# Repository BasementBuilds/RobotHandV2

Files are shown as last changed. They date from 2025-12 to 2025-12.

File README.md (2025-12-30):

# RobotHandV2
This has most of the files relating to the code, and mechanics of the robot hand and arm band.

If you have any more detailed questions, reach out to me on instagram or email at basementbuilds48@gmail.com

This should be taken as resource for different ideas, not as a tutorial to copy exactly.
The main code is run on the esp32 on the robot hand. There is also code for the glove, and the arm band, which send messages to the main robot on how to move.

If you try to use this code for some reason, make sure anytime 2 esps need to communicate wirelessly, they have the correct mac address in the code.

Neural network:
I also included some python code and training data related to the neural network I tried making.
I also included a paper explaining the neural network that I made for a class project.

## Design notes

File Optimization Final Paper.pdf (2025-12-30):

Using Gradient Descent to Optimize A Neural Network For Classification of Hand Gestures

Abstract

Electric prosthetic hands are typically controlled using two electromyography sensors. While they have been used for decades, they exhibit significant disadvantages that recent research has tried to solve using arrays of force sensors. To convert these signals into accurate predictions of the hand gesture the user is attempting to make, an algorithm such as an artificial neural network must be used. This paper details the process of training a neural network to accurately predict hand gestures based on sensor data using the method of steepest gradient descent. Overall, the method was successful, in correctly classifying 91% of signals, although further research would be beneficial in further improving the accuracy of the model.

Motivating problem

Most modern powered prosthetic hands are controlled by the user through EMG (electromyography) signals. Typically, two sensors are placed on the user's residual forearm, and by flexing one of the two main forearm muscles, the user can ‘swipe through’ a set of pre-programmed hand grips/gestures.

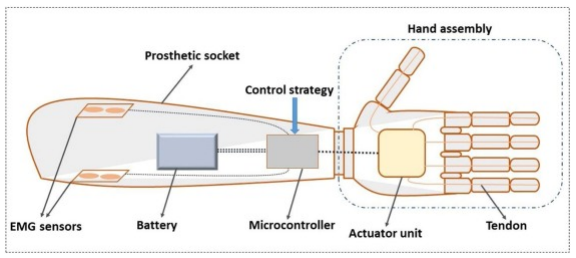
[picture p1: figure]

This has been a relatively reliable method of control for decades now, however it comes with its own drawbacks. Many users say that the complication of switching to the correct grip, and lack of fine control of their prosthetic are the main reason they dislike their prosthetic or avoid using it (1). Additionally, EMG signals typically have high noise, and become unreliable when misplaced or subject to moisture from sweat (2). This has led researchers to explore using force myography (FMG) (force sensors) as a replacement or supplement for EMG signals in prosthetic use. FMG sensors are cheaper, can be more densely packed in a small area, and are not affected by sweat or noise to the same degree. In order for this method to work, FMG data must be directly interpreted into hand grip selection (rather than cycling through grips).

Literature Review

A 2023 study by Rehman et. al. found that using force sensors was a viable method to predict hand gestures. In their research, a 7 sensor band using a support vector machine algorithm to classify 5 gestures had an accuracy of 91.6% (2). A similar study from the University of Windsor used the same algorithm with a slightly higher accuracy of 93% (3). A 2025 study from Meta’s Reality lab was able to achieve over 90% accuracy of gesture recognition using an EMG wristband and a neural network architecture (4). While the first two studies mentioned achieved high accuracy using the SVM algorithm, they only had a few (<10) participants, and it’s unclear how these results would transfer to a new user, one with a different physiology. The Meta study had over 6,00 participants and was only able to achieve good results for the general population by training neural networks over thousands of participants. While the model they used (neural network with over 15 layers) is far beyond what will be discussed in this paper, it proves that neural networks are powerful and scalable enough to tackle the motivating problem.

Background

In order to collect enough FMG data to predict hand gestures, an array of pressure sensors in a small area is needed. Previous research in this field has used commercially available individual force sensor resistors to accomplish this. While this has worked, a fully integrated design was chosen for its cost effectiveness and ability to increase sensor density in future iterations. The sensor mainly consists of a sheet of velostat sandwiched between two layers of rows of copper tape running perpendicularly. Velostat is a polymer impregnated with electrically conductive carbon black. As pressure is applied, the carbon black particles come closer to each other, reducing electrical resistance. Each of these ‘resistors’ is placed in series with a constant resistor forming a voltage divider circuit, as can be seen in the schematic below. Voltage is applied across both resistors, and the voltage across the constant resistor is measured by a microcontroller (ESP32), giving us the data we need to implement FMG control.

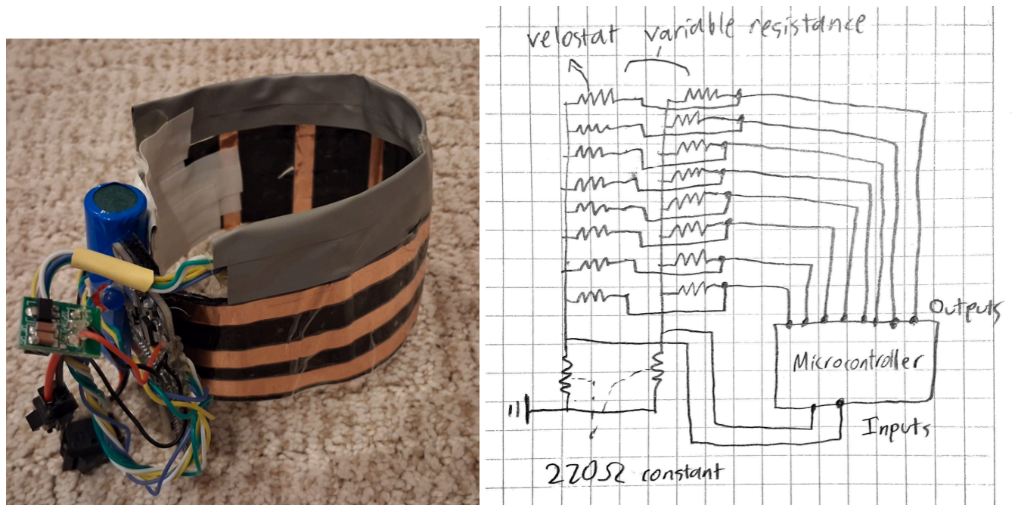
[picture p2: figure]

Below is a section of code written in the Arduino programming language that measures the voltage difference of one column of sensors (2 sensors).

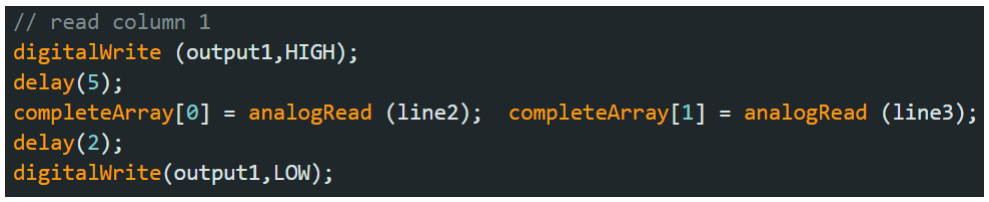
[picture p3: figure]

In order for this method to work, FMG data must be directly interpreted into hand grip selection (rather than cycling through grips). To do this, an artificial neural network (ANN) was used. An ANN connects a set of input nodes with a set of output nodes through an intermediary set of nodes often referred to as a ‘hidden layer’. Each node in a layer is taken as a weighted sum of the prior layer passed through an activation function. (each previous node is multiplied by a parameter ‘weight’, summed, added to another parameter ‘bias’ and passed through a non linear ‘activation’ function). The purpose of the activation function is to make the ANN non linear, which allows the network to better handle complex, high dimensional problems. The diagram below represents a simple neural network where the lines connecting the layers represent the weights.

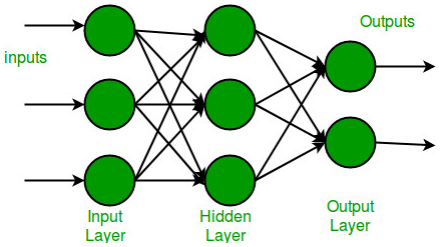
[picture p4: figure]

For the purposes of this paper, what is important to understand is that a neural network can be thought of as a very large non-linear function with many parameters (weights and biases). These parameters all must be adjusted based on training data in order to give the correct output for the given input. In concept, this can be thought of as similar to polynomial regression, where a polynomial can be fit to a set of data by tweaking the polynomial’s coefficients.
The method to adjust the ANN weights and biases is called back propagation. To train the ANN, training data (in this case, about 200 examples), which contains both the inputs and outputs, is used. The first training example input will be plugged into the neural network, with the weights and biases initially randomized. The output of the ANN will then be compared to the true output, using a cost function. The cost is a function of all of the ANN’s weights and biases. The more ‘wrong’ the ANN is in its prediction, the higher the cost will be. The gradient of the cost function can then be found, which will be explained in more detail in the approach section. The negative of the gradient shows the direction and magnitude of the changes to the weights and biases that will lead to the steepest decrease in the cost function, thus improving the accuracy of the ANN. This is a process known as steepest gradient descent. This process is then repeated for all (roughly 200) of the training examples, until the cost has reached a minimum.

Approach

The input of the neural network is the 16 FMG sensor values, and the output is 4 nodes corresponding to hand gestures (open, close, point, pinch) respectively. For example, an output of [0,0,1,0] would correspond to the ‘point’ gesture. After testing several structures, an ANN with 1 hidden layer of 18 nodes (along with an input layer of 16 nodes and output of 4 nodes) using the ‘leaky ReLu’ activation function was chosen, as it was the least computationally expensive model that worked well.

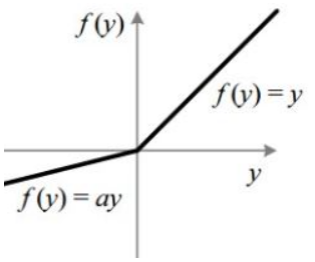
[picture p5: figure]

The graph above represents the leaky ReLu function. In this project, an (a) value of 0.1 was used.
This model has 382 weights and biases which are the design variables that must be adjusted. While the neural network can seem very complicated at first, it can be implemented relatively simply as seen by the few lines of python code below.

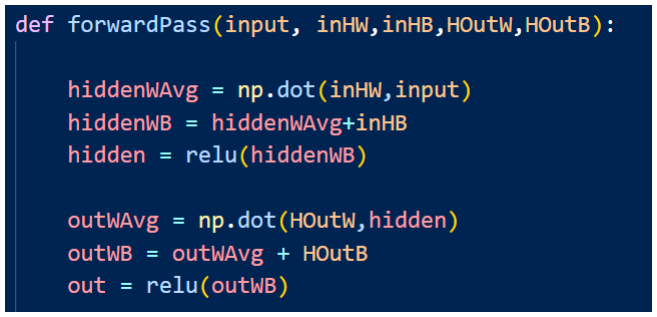
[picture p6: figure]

In the code, inHW and inHB are the weights and biases between the input and hidden layers, and HOutW and HOutB are the parameters between the hidden and output layers. The next step is to find the cost of the neural network, which is a function of all the parameters (weights and biases). This will be the objective function that we will seek to minimize. We will also add an inequality constraint to each of the weights to limit their absolute value. Research has shown that doing so helps to prevent the neural network from overfitting (5), which is represented in the diagram below.

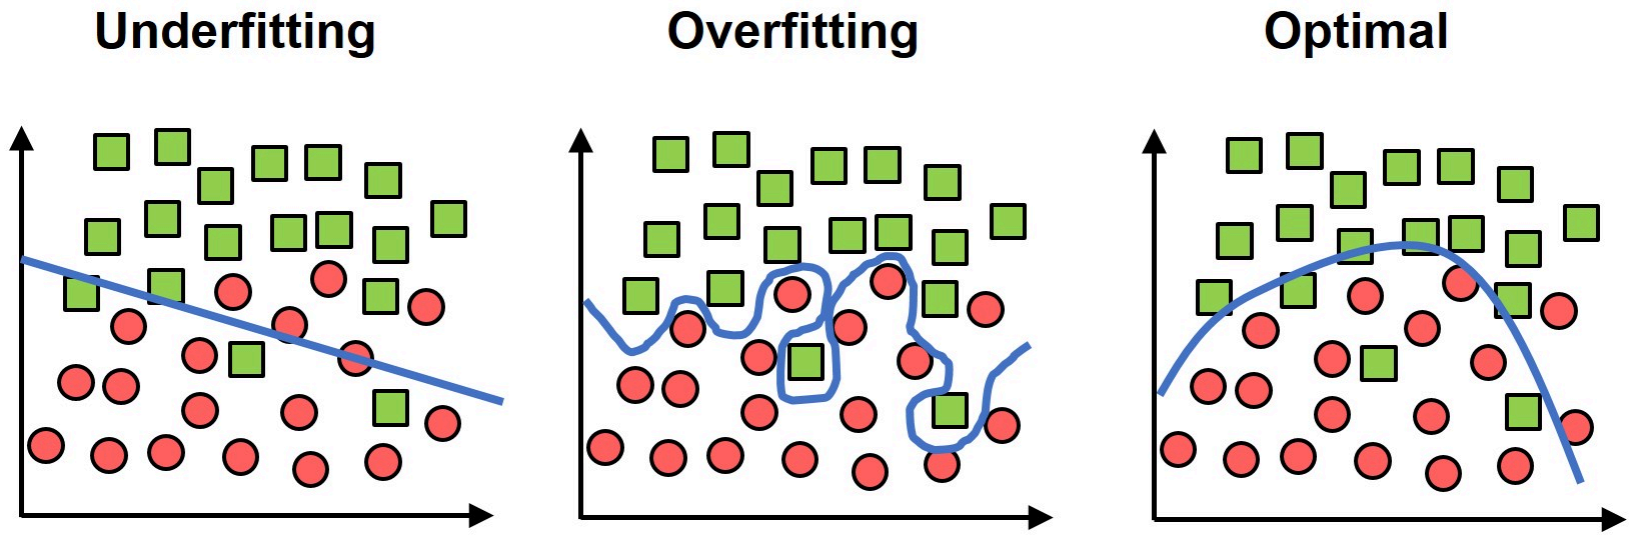
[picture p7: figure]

The optimization problem can now be expressed in the standard form as seen below, where w1 and b1 are the parameters between the input and hidden layer, and w2 and b2 are the parameters between the hidden and output layer. w1 and w2 are matrices, and b1 and b2 are vectors. In the summation steps, 4 is representative of the 4 output neurons, 1 for each hand gesture, and T represents the total number of training examples.

## Min

Subject to:

The code below calculated the cost function for a single training example, which can then be summed across the entire dataset.

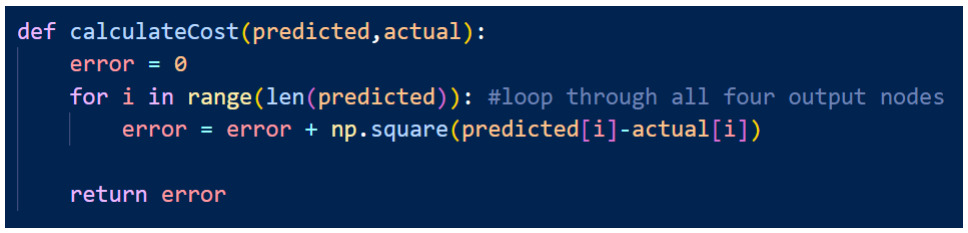
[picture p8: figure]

As previously mentioned, the approach to minimize the cost function was decided to be steepest gradient descent. The first step in this process is to determine the gradient of the cost function. The gradient in simpler terms can be thought of as the slope of the function. The gradient is a vector that for each independent variable (weights and biases), will represent the direction and magnitude of steepest ascent. For example, if a value in the gradient vector corresponding to a certain weight (Wa) is positive, that means that increasing Wa will increase the overall cost function. However, we want to minimize the cost function, so we will find the negative of the gradient. We must find the partial derivative of the cost with respect to each weight and bias.
To do this, the chain rule from calculus must be applied. The partial derivative of a weight between the hidden and output layer for example, is equal to the product of partial derivative of the cost with respect to the output node, multiplied by the partial derivative of the output node with respect to the activation function, multiplied by the partial derivative of the weighted sum (output node before it was passed through the activation function) with respect to the weight as is represented by the equation below.

Similarly, the partial derivative of the cost with respect to a bias in the output layer is given below. The last term of dz/db is equal to 1 and thus can be dropped.

The partial derivative of the cost with respect to a weight between the input and hidden layers is given below.

The partial derivative of the cost with respect to a bias in the hidden layer is given below.

The partial derivative of the cost with respect to the hidden layer node (first term in the above equations) is given below.

Below is the code that calculates the partial derivatives of the cost with respect to the parameters between the hidden and output layers.

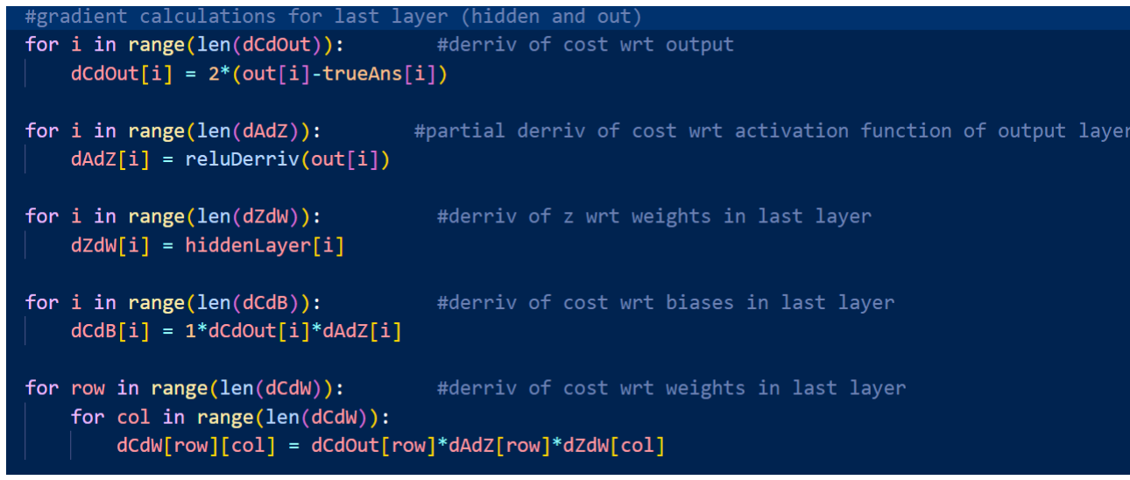
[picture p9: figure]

Likewise, the code for the partial derivatives of the cost with respect to the parameters between the input and hidden layer is given below.

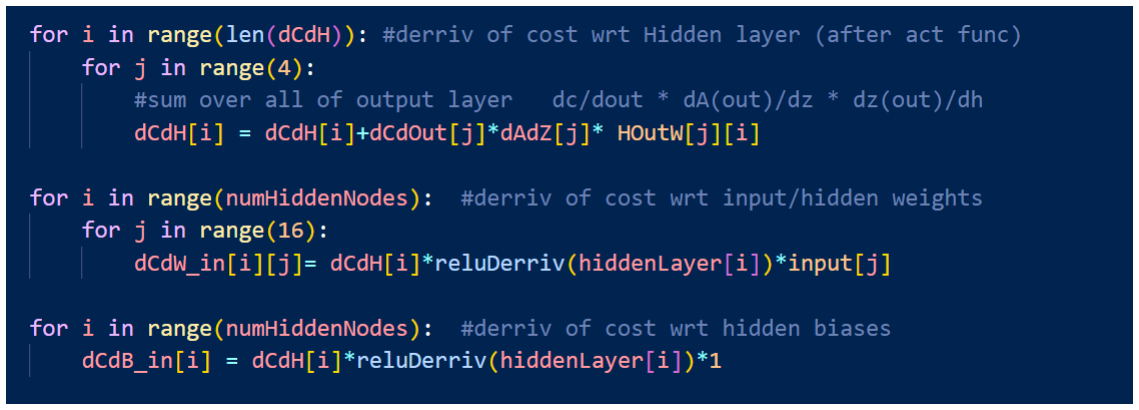
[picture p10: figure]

Once the gradient has been calculated, the next step is to adjust all 382 design variables (weights and biases) to reduce the cost function, thereby making the model overall more accurate at correctly recognizing the 4 hand gestures. The way to do this is by taking the negative of the gradient, multiplying it by a scalar (fraction to reduce magnitude, prevents oscillations and overshooting), and adding the results to the design variables. This process is repeated over all training examples, until the cost function reaches a minimum. The code to accomplish this step of gradient descent is shown below.

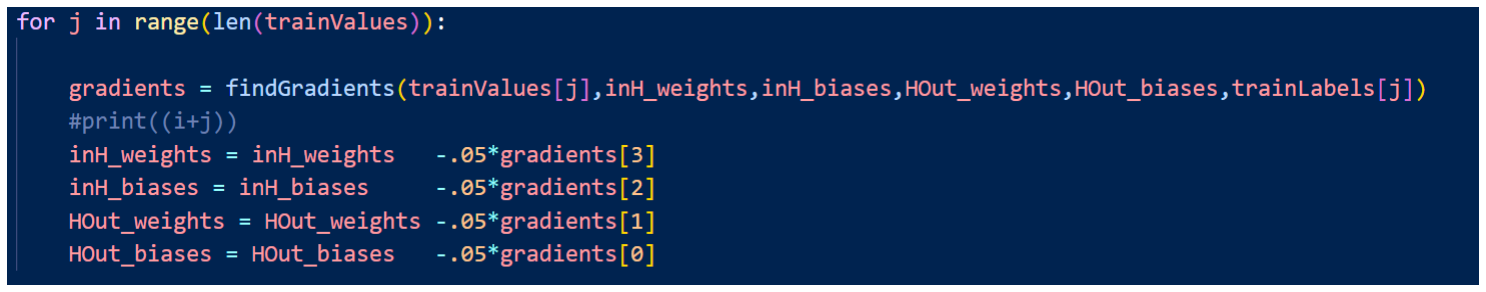
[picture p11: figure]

Here, the step size was decided to be 0.05 based on experimentation. A more analytical way to determine hyperparameters such as step size will be explored further in the results and discussion section.

Results

Overall, the method of gradient descent worked well. The graph below shows the cost of the neural network during the process of gradient descent.

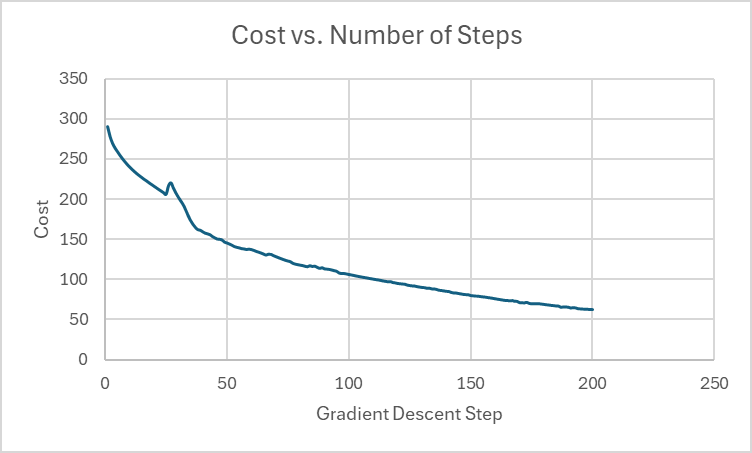
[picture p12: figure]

After 200 gradient descent steps, the cost fell from 289.8 to 62.9, which shows that the gradient descent method was effective. However, the cost is somewhat of an arbitrary number that is relative to the size of the dataset, and doesn’t directly tell us what we want to know, which is how accurate the neural network is at predicting hand gestures. To find the accuracy, a second dataset is then passed through the neural network. This ‘testing’ dataset of about 100 examples is completely separate from the training dataset, and the correct answer is not used to influence the output of the network. The accuracy of the neural network in regards to new data is shown in the graph below.

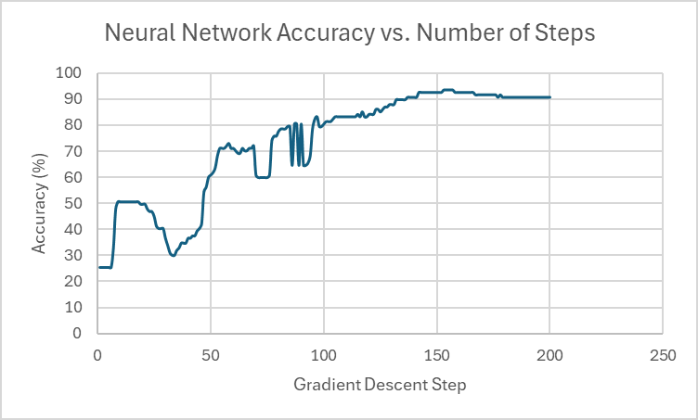
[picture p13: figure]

The accuracy increased over 200 gradient descent steps from 25.2% to 91.6%, which is in line with previous research in this field, albeit somewhat on the low side.

Discussion and Conclusion

Several interesting observations can be made from the results. While the accuracy of the network increasing while the cost decreases is to be expected, the cost decreased in a mostly smooth manner, while the accuracy oscillates somewhat erratically while trending upwards. This could be due to several factors, including small training and testing datasets, or perhaps possibly due to the network overfitting in some instances.
Another observation during testing was that the results varied across different training runs. This is somewhat expected due to the parameters initially being randomized. However, the network in some cases was unable to improve accuracy in a meaningful way, as seen by the graphs below.

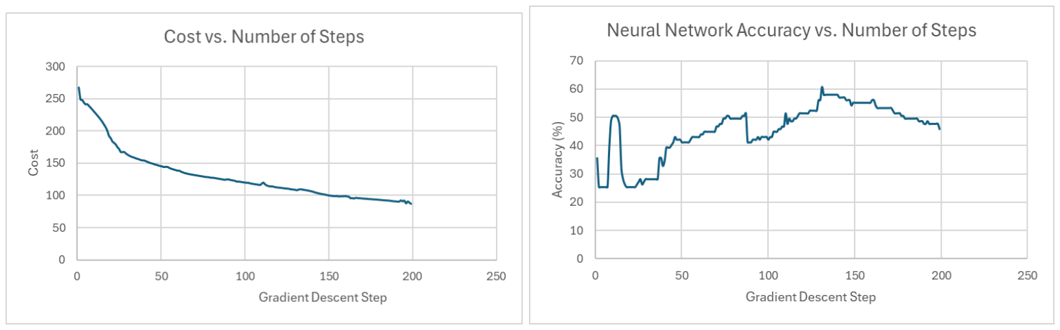
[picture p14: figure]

Here, the model plateaued at an accuracy of only 46%. This could be due to the model optimizing into a high local minimum, rather than a global minimum, which can be visualized by the image below.

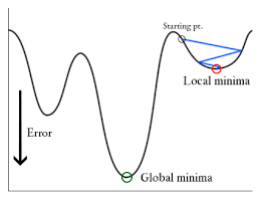
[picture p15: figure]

A third observation can be made in regards to the actual parameters of the network. Neural networks are typically thought of as a ‘black box’ that are impossible to understand the inner workings of. This is especially true of deep learning models with dozens of layers and millions of parameters, but this model is relatively small, and interesting effects can be observed. From a small selection of input data (seen below), we can see that some sensors change more than others based on the grip pattern. Here, it can be noticed that the first sensor varies significantly, over 200 units between different grips, while the sixteenth sensor only varies a couple of units between grips.

After training the model, the difference in weight values of the two sensors was measured. The sum of changes to weights connected to the first sensor node was 39.2, while the sum of changes to the sixteenth sensor was only 20.6. If we observe individual weights, it becomes clear that the neural network ‘decided’ that the first sensor should be more influential than the sixteenth sensor. For example, the weight connecting the first sensor to the sixth hidden node changed from -.62 to 7.75. The corresponding weight for the sixteenth sensor only changed from 0.59 to 1.0.

While this paper demonstrated that a neural network could be used to accurately classify hand gestures, more research needs to be done to improve accuracy and make this solution commercially viable. Many of the ‘hyper’ parameters of the network such as number of layers, number of hidden nodes, activation function, and step size were chosen through simple trial and error, or randomly. These hyper parameters could be in themselves optimized, through methods such as genetic algorithms. Further optimization could also be done to the physical sensor arm band, which showed promising results for future research.

References

1. Pylatiuk C, Schulz S, Döderlein L. Results of an Internet survey of myoelectric prosthetic hand users. Prosthet Orthot Int. 2007 Dec;31(4):362-70. doi:
10.1080/03093640601061265. PMID: 18050007.\
2. Rehman, M. U., Shah, K., Haq, I. U., Iqbal, S., Ismail, M. A., & Selimefendigil, F. (2023). Assessment of Low-Density Force Myography Armband for Classification of Upper Limb Gestures. Sensors, 23(5), 2716. https://doi.org/10.3390/s23052716
3. M. Anvaripour and M. Saif, "Hand gesture recognition using force myography of the
| forearm activities and optimized features," 2018 IEEE International Conference on
| Industrial Technology (ICIT), Lyon, France, 2018, pp. 187-192, doi:
| 10.1109/ICIT.2018.8352174. keywords: {Feature
| extraction;Sensors;Muscles;Optimization;Mathematical model;Gesture
| recognition;Support vector machines;Force Myography;Hand gestures;Feature
| extraction;Multiobjective optimization},
4. Kaifosh, P., Reardon, T.R. & CTRL-labs at Reality Labs. A generic non-invasive
| neuromotor interface for human-computer interaction. Nature 645, 702–711 (2025).
| https://doi.org/10.1038/s41586-025-09255-w
5. Brownlee, Jason. “A Gentle Introduction to Weight Constraints in Deep Learning.”
| MachineLearningMastery.Com, 6 Aug. 2019,
| machinelearningmastery.com/introduction-to-weight-constraints-to-reduce-generalization
| -error-in-deep-learning/.

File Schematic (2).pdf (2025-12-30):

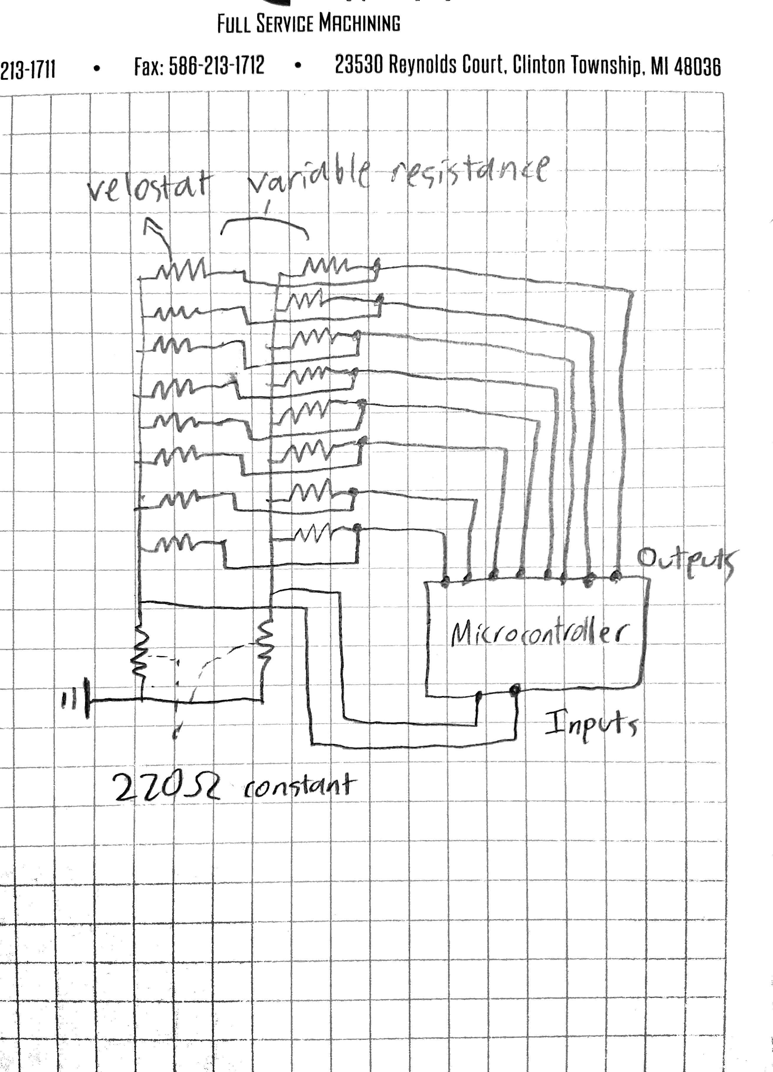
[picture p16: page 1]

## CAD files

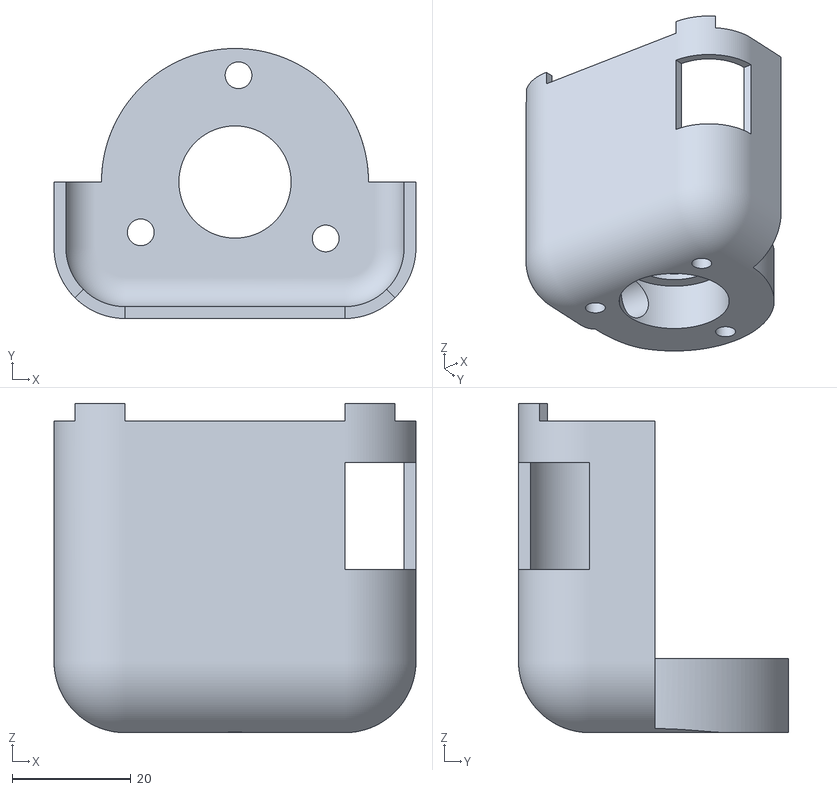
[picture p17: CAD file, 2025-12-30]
Github STLs/forearmMain.stl
61.0 x 45.5 x 55.5

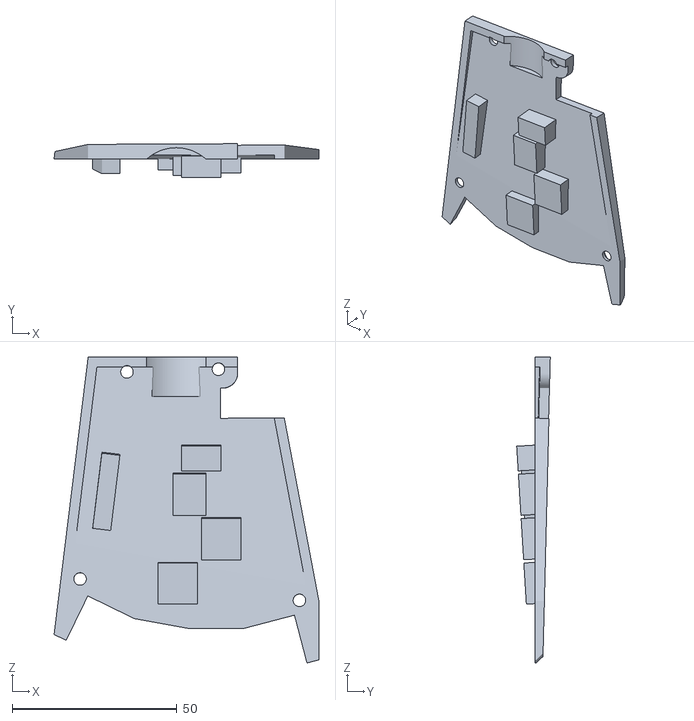
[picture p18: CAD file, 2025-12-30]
Github STLs/palmTop.stl
80.3 x 10.2 x 92.8

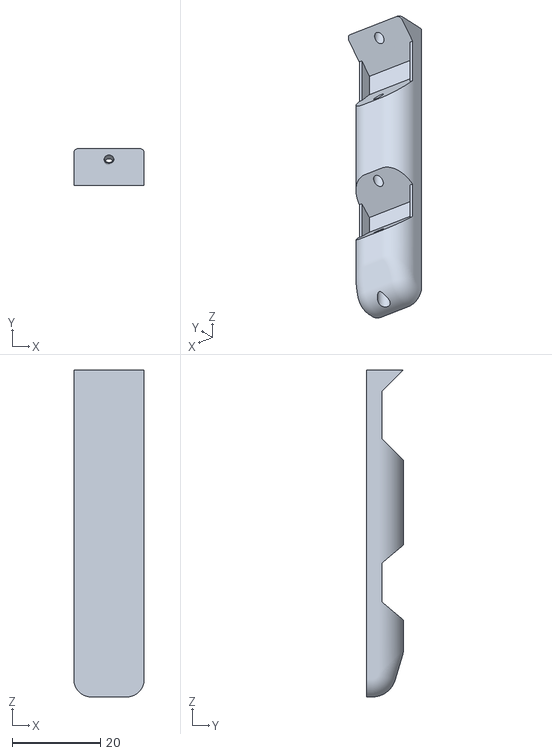
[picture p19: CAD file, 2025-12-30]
Github STLs/thumbTpu.stl
16.0 x 8.35 x 74.2

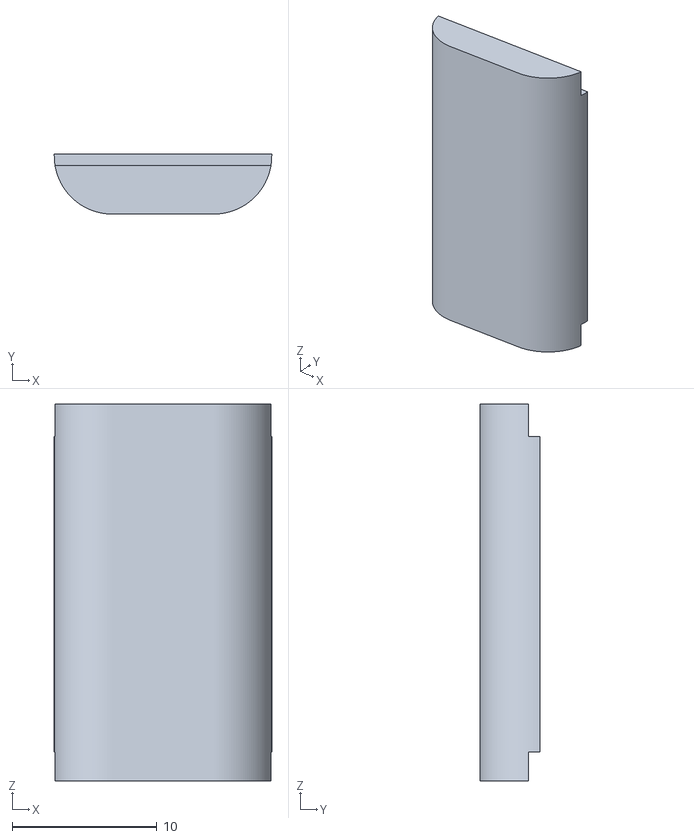
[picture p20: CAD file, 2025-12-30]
Github STLs/plaBacking2.stl
15.0 x 4.15 x 26.0

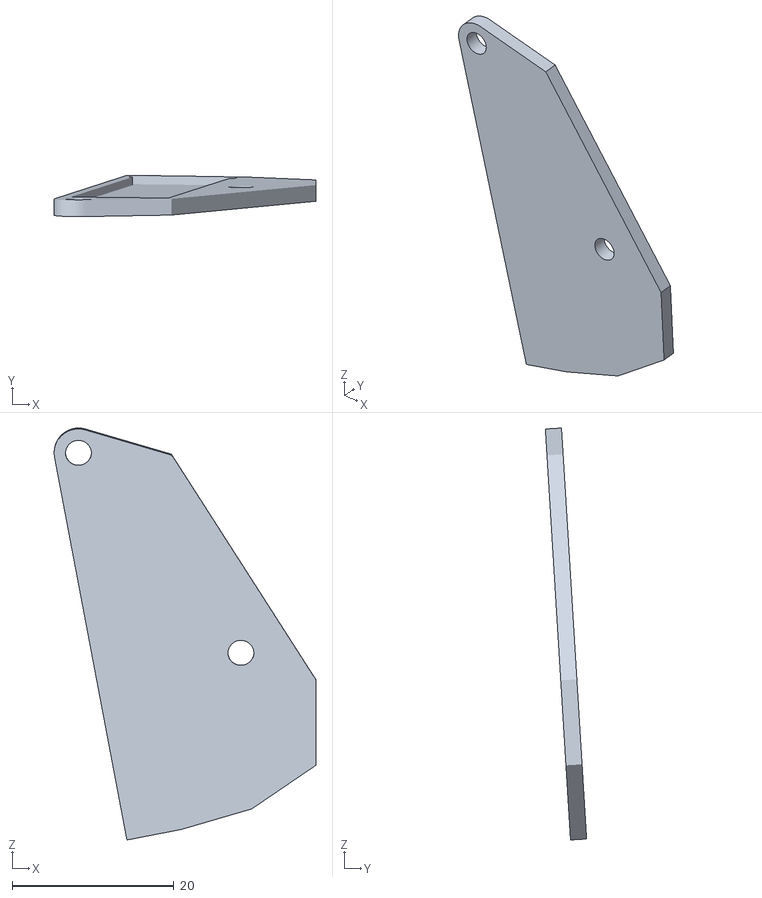
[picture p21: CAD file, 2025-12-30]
Github STLs/thumbCover.stl
32.3 x 5.10 x 50.9

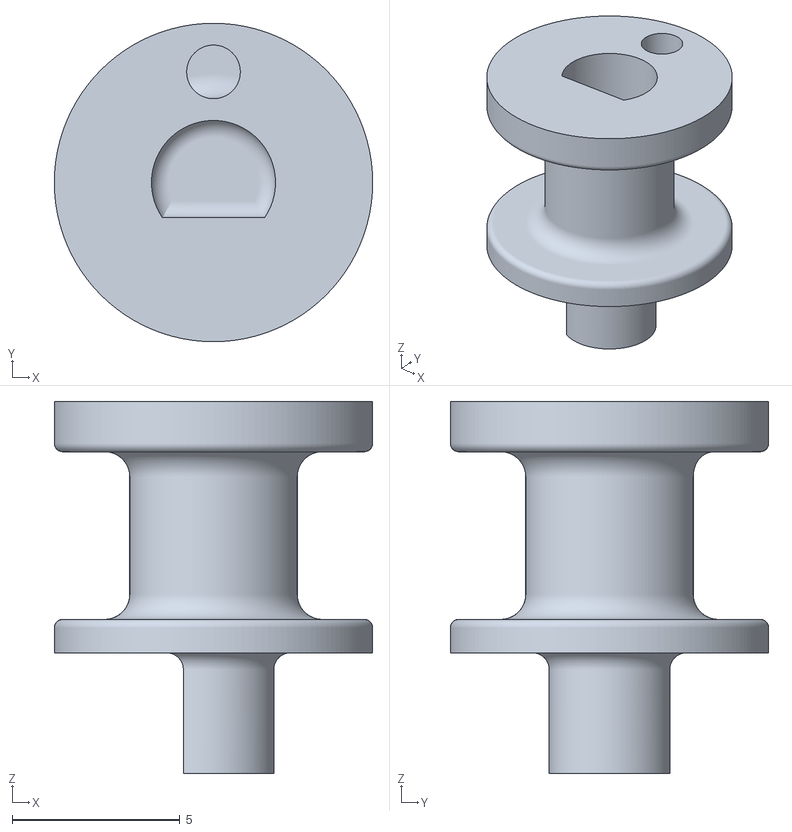
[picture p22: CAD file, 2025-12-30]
Github STLs/winch.stl
9.50 x 9.50 x 11.1

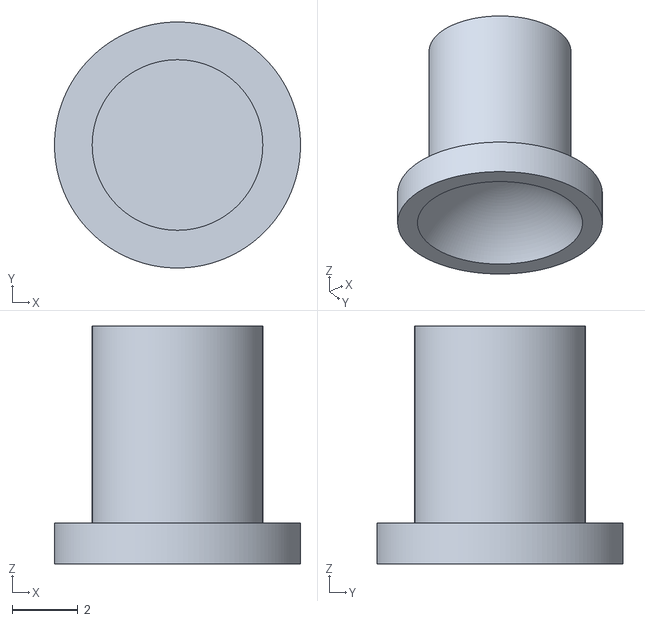
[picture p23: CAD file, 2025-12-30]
Github STLs/bbCarrier.stl
7.50 x 7.50 x 7.25

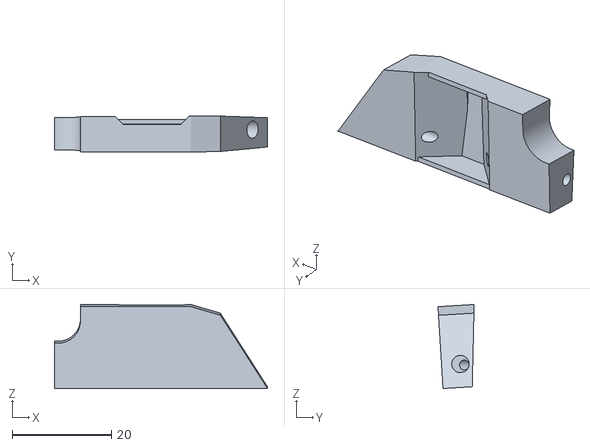
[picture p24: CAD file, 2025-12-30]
Github STLs/thumbJoint.stl
43.0 x 7.27 x 16.9

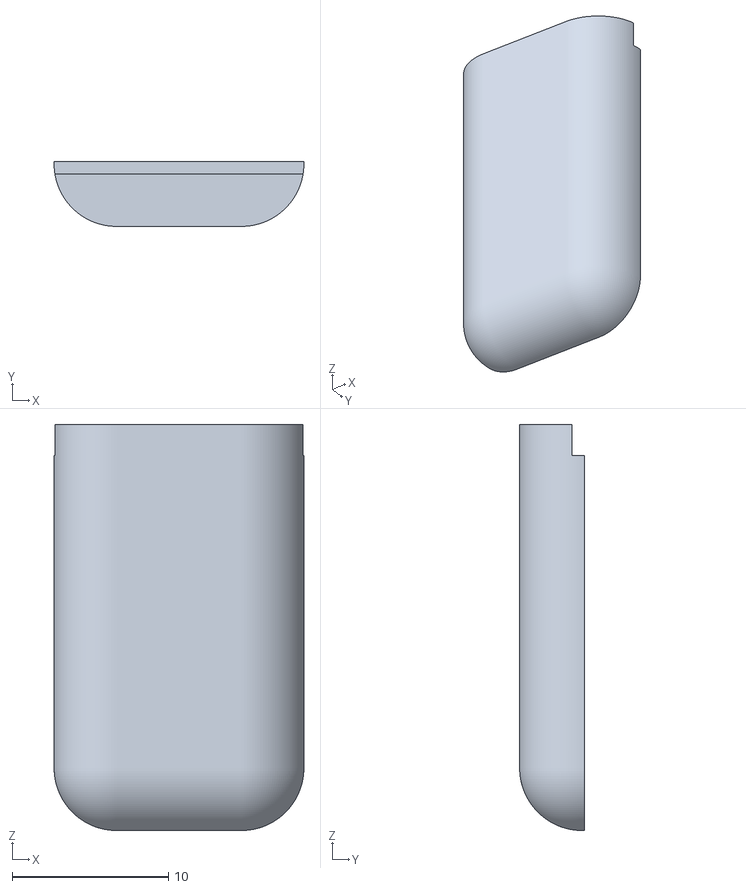
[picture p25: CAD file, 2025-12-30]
Github STLs/thumbBacking1.stl
16.0 x 4.15 x 26.0

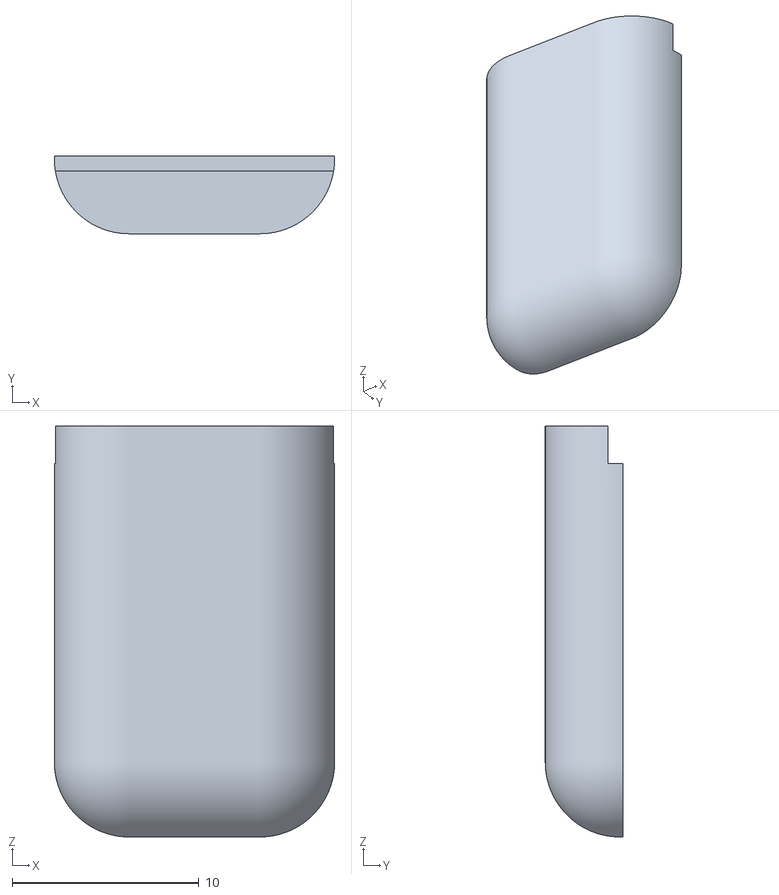
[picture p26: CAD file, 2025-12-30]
Github STLs/plaBacking.stl
15.0 x 4.15 x 22.0

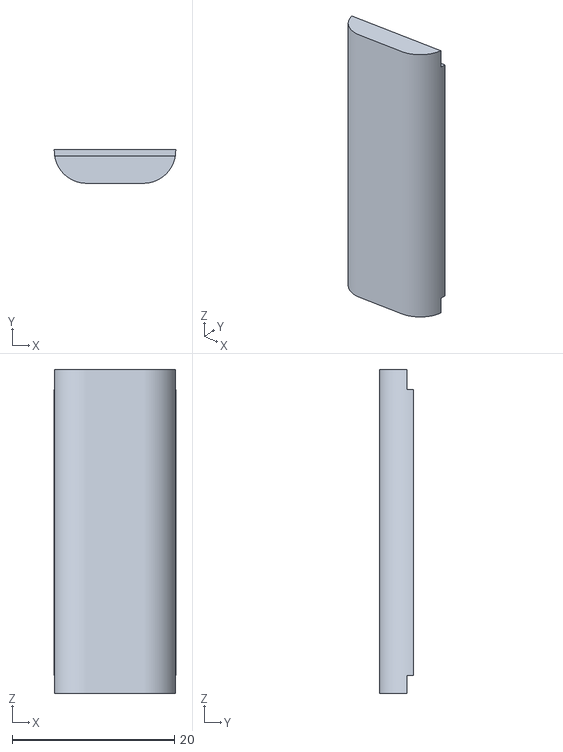
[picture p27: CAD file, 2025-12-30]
Github STLs/plaBacking3.stl
15.0 x 4.15 x 40.0

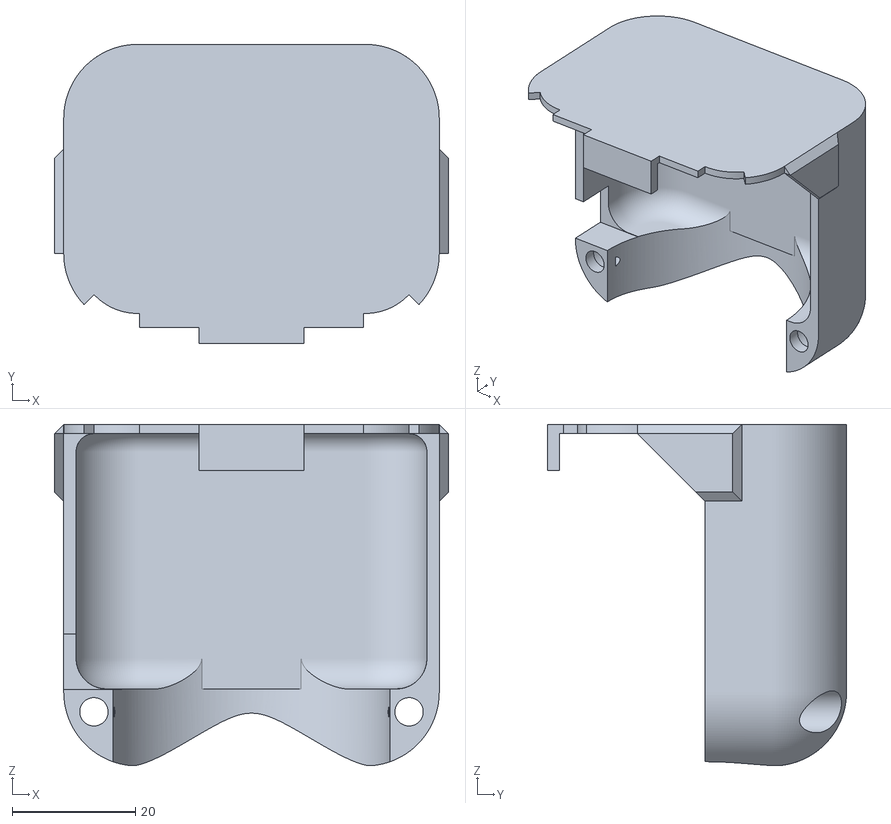
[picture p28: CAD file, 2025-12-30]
Github STLs/forearmTop.stl
64.0 x 48.6 x 55.5

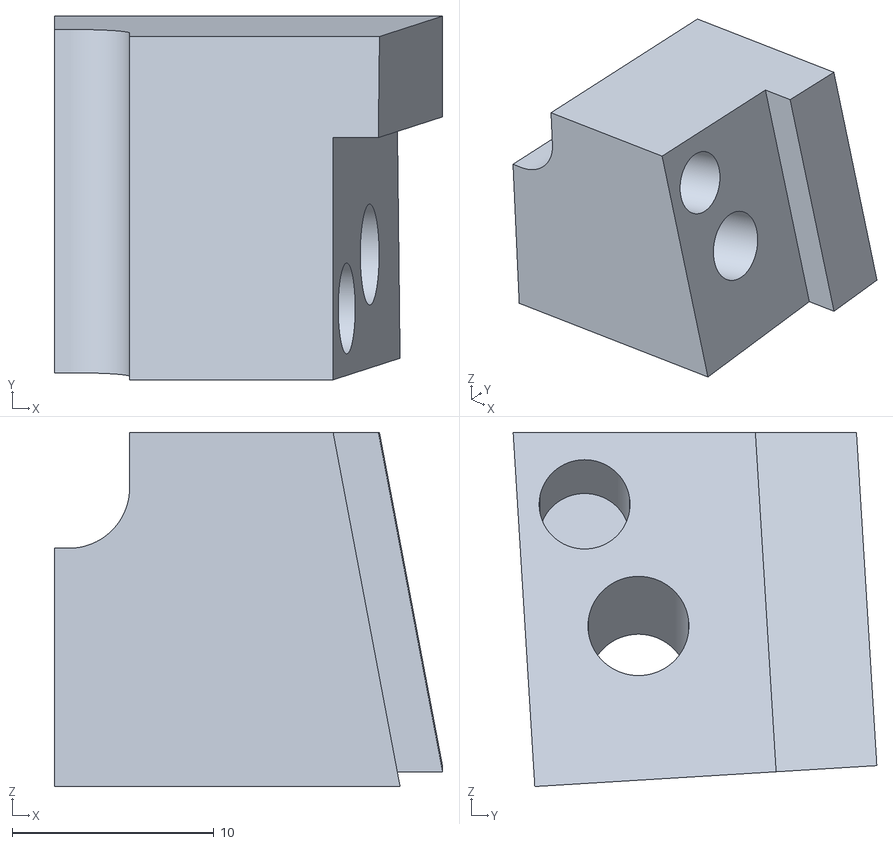
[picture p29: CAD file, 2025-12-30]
Github STLs/plaJointConnector.stl
19.2 x 18.0 x 17.5

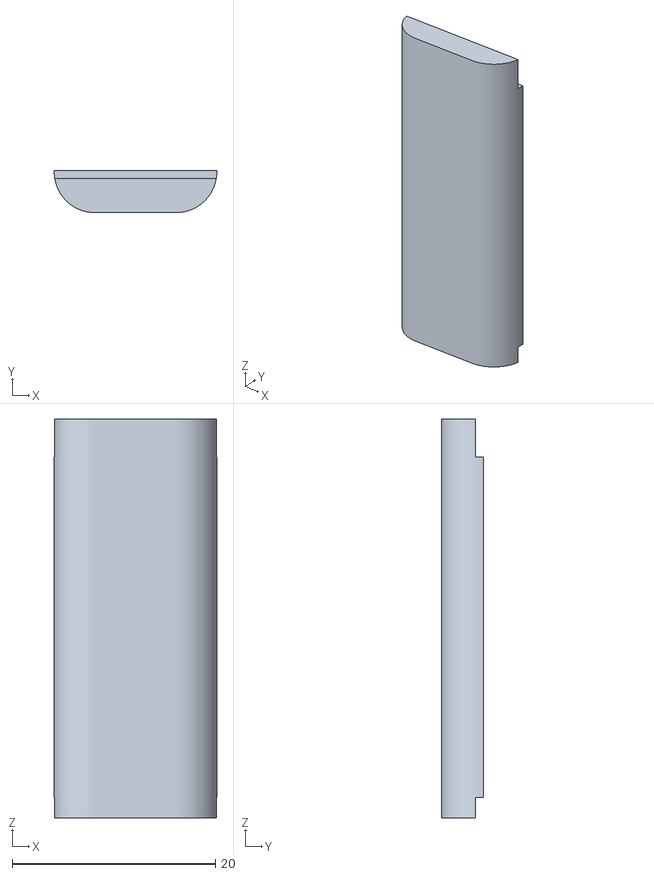
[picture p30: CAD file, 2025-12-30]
Github STLs/thumbBacking2.stl
16.0 x 4.15 x 39.2

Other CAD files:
Github STLs/wideWinchThumb (1).stl
Github STLs/tpuDigits.stl
Github STLs/palmBase.stl
Github STLs/detents.stl
Github STLs/forearmCap.stl
Github STLs/threadedInsertHolder.stl
Github STLs/thumbBase.stl

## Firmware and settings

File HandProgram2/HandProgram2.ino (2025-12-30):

#include <esp_now.h>
#include <WiFi.h>

typedef struct struct_message {
    float Adest;
    float Bdest;
    float Cdest;
    float Ddest;
    float Edest;
    float Fdest;

} struct_message;
struct_message myData;
void OnDataRecv(const uint8_t * mac, const uint8_t *incomingData, int len) {
  memcpy(&myData, incomingData, sizeof(myData));
  //Serial.print("Bytes received: ");
}



const int freq = 1000;
const int res = 8;
// motor PID control variables
int motorLimit = 240;
int kp = 450;
int kd = 300;
int kpT = 450;
int kdT = 2100;

// A = middle finger B = pointer finger C = ring finger D = pinky

float AcalculatedPos = 10.6;
int ArawPotValue = 0;
int ArawPotValuePrev = 0;
int Aoffset = 2000;
int Aadjusted = 0;
int AadjustedPrev = 0;

float BcalculatedPos = 10.0;
int BrawPotValue = 0;
int BrawPotValuePrev = 0;
int Boffset = 2000;
int Badjusted = 0;
int BadjustedPrev = 0;

float CcalculatedPos = 10.0;
int CrawPotValue = 0;
int CrawPotValuePrev = 0;
int Coffset = 2000;
int Cadjusted = 0;
int CadjustedPrev = 0;

float DcalculatedPos = 10.0;
int DrawPotValue = 0;
int DrawPotValuePrev = 0;
int Doffset = 2000;
int Dadjusted = 0;
int DadjustedPrev = 0;


float EcalculatedPos = 10.0;
int ErawPotValue = 0;
int ErawPotValuePrev = 0;
int Eoffset = 2000;
int Eadjusted = 0;
int EadjustedPrev = 0;

float FcalculatedPos = 10.0;
int FrawPotValue = 0;
int FrawPotValuePrev = 0;
int Foffset = 2000;
int Fadjusted = 0;
int FadjustedPrev = 0;

//  A is middle, B is pointer, C is Ring, D is pinky, E is thumb fold, F is thumb digits

float Agoal = 10.6;
float Aerror, AprevError;
int Apin1 = 2, Apin2 = 4;                   // motor signal pins
const int Achan1 =0, Achan2 = 1;            // channells
int Aout1 = 0, Aout2 = 0;   

float Bgoal = 10.2;
float Berror, BprevError;
int Bpin1 = 17, Bpin2 = 16;                   // motor signal pins
const int Bchan1 =2, Bchan2 = 3;            // channells
int Bout1 = 0, Bout2 = 0; 

float Cgoal = 10.3;
float Cerror, CprevError;
int Cpin1 = 13, Cpin2 = 12;                   // motor signal pins
const int Cchan1 =4, Cchan2 = 5;            // channells
int Cout1 = 0, Cout2 = 0; 

float Dgoal = 9.5;
float Derror, DprevError;
int Dpin1 = 5, Dpin2 = 18;                   // motor signal pins
const int Dchan1 =6, Dchan2 = 7;            // channells
int Dout1 = 0, Dout2 = 0; 

float Egoal = 10.2;
float Eerror, EprevError;
int Epin1 = 23, Epin2 = 22;                   // motor signal pins
const int Echan1 =8, Echan2 = 9;            // channells
int Eout1 = 0, Eout2 = 0; 

float Fgoal = 0.8;
float Ferror, FprevError;
int Fpin1 = 21, Fpin2 = 19;                   // motor signal pins
const int Fchan1 =10, Fchan2 = 11;            // channells
int Fout1 = 0, Fout2 = 0; 



void setup() {
  // put your setup code here, to run once:
  Serial.begin (115200);
  WiFi.mode(WIFI_STA);
  if (esp_now_init() != ESP_OK) {
    //Serial.println("Error initializing ESP-NOW");
    return;
  }
  esp_now_register_recv_cb(esp_now_recv_cb_t(OnDataRecv));


  // Motor A setup
  ledcSetup(Achan1,freq,res);  ledcSetup(Achan2,freq,res);
  ledcAttachPin(Apin1,Achan1); ledcAttachPin(Apin2,Achan2);
  ledcWrite(Achan1, 0); ledcWrite(Achan2, 0);

  ledcSetup(Bchan1,freq,res);  ledcSetup(Bchan2,freq,res);
  ledcAttachPin(Bpin1,Bchan1); ledcAttachPin(Bpin2,Bchan2);
  ledcWrite(Bchan1, 0); ledcWrite(Bchan2, 0);

  ledcSetup(Cchan1,freq,res);  ledcSetup(Cchan2,freq,res);
  ledcAttachPin(Cpin1,Cchan1); ledcAttachPin(Cpin2,Cchan2);
  ledcWrite(Cchan1, 0); ledcWrite(Cchan2, 0);

  ledcSetup(Dchan1,freq,res);  ledcSetup(Dchan2,freq,res);
  ledcAttachPin(Dpin1,Dchan1); ledcAttachPin(Dpin2,Dchan2);
  ledcWrite(Dchan1, 0); ledcWrite(Dchan2, 0);

  ledcSetup(Echan1,freq,res);  ledcSetup(Echan2,freq,res);
  ledcAttachPin(Epin1,Echan1); ledcAttachPin(Epin2,Echan2);
  ledcWrite(Echan1, 0); ledcWrite(Echan2, 0);

  ledcSetup(Fchan1,freq,res);  ledcSetup(Fchan2,freq,res);
  ledcAttachPin(Fpin1,Fchan1); ledcAttachPin(Fpin2,Fchan2);
  ledcWrite(Fchan1, 0); ledcWrite(Fchan2, 0);

  pinMode(32,INPUT); pinMode(33,INPUT);pinMode(34,INPUT);pinMode(35,INPUT);pinMode(36,INPUT);pinMode(39,INPUT);


}

void loop() {
  
  if (Serial.available() > 0) {  // Check if data is available to read
    Fgoal = Serial.parseFloat();  // Read and parse the float value
    while (Serial.available() > 0) { Serial.read(); }
  }

  //receive comands from glove

  Agoal = constrain(myData.Adest,8.5,10.6);
  Bgoal = constrain(myData.Bdest,7.9,10.2);
  Cgoal = constrain(myData.Cdest,10.3,12.5);
  Dgoal = constrain(myData.Ddest,9.5,11.7);
  Egoal = constrain(myData.Edest,9.5,10.2);
  Fgoal = constrain(myData.Fdest,0.2,0.8);



  Agoal = constrain(Agoal,8.5,10.6);
  Bgoal = constrain(Bgoal,7.9,10.2);
  Cgoal = constrain(Cgoal,10.3,12.5);
  Dgoal = constrain(Dgoal,9.5,11.7);
  Egoal = constrain(Egoal,9.5,10.2);
  Fgoal = constrain(Fgoal,0.2,0.8);

  //find motor positions
  ArawPotValue = analogRead(34);
  if(ArawPotValue>=Aoffset){Aadjusted = ArawPotValue - Aoffset;}  else{ Aadjusted = ArawPotValue + (4095 - Aoffset); }
  AcalculatedPos = getMotorPos(AcalculatedPos,Aadjusted,AadjustedPrev);

  BrawPotValue = analogRead(35);
  if(BrawPotValue>=Boffset){Badjusted = BrawPotValue - Boffset;}  else{ Badjusted = BrawPotValue + (4095 - Boffset); }
  BcalculatedPos = getMotorPos(BcalculatedPos,Badjusted,BadjustedPrev);

  CrawPotValue = analogRead(32);
  if(CrawPotValue>=Coffset){Cadjusted = CrawPotValue - Coffset;}  else{ Cadjusted = CrawPotValue + (4095 - Coffset); }
  CcalculatedPos = getMotorPos(CcalculatedPos,Cadjusted,CadjustedPrev);
  
  DrawPotValue = analogRead(33);
  if(DrawPotValue>=Doffset){Dadjusted = DrawPotValue - Doffset;}  else{ Dadjusted = DrawPotValue + (4095 - Doffset); }
  DcalculatedPos = getMotorPos(DcalculatedPos,Dadjusted,DadjustedPrev);
 
  ErawPotValue = analogRead(36);
  if(ErawPotValue>=Eoffset){Eadjusted = ErawPotValue - Eoffset;}  else{ Eadjusted = ErawPotValue + (4095 - Eoffset); }
  EcalculatedPos = getMotorPos2(EcalculatedPos,Eadjusted,EadjustedPrev);

  FrawPotValue = analogRead(39);
  if(FrawPotValue>=Foffset){Fadjusted = FrawPotValue - Foffset;}  else{ Fadjusted = FrawPotValue + (4095 - Foffset); }
  FcalculatedPos = getThumbMotorPos(Fadjusted);
  
  
  //give motor power to move towards the goal
  Aerror = Agoal - AcalculatedPos;
  pidController(Aerror, AprevError, Aout1, Aout2);
  ledcWrite(Achan1, Aout1); ledcWrite(Achan2, Aout2);
  Berror = Bgoal - BcalculatedPos;
  pidController(Berror, BprevError, Bout1, Bout2);
  ledcWrite(Bchan1, Bout1); ledcWrite(Bchan2, Bout2);
  Cerror = Cgoal - CcalculatedPos;
  pidController(Cerror, CprevError, Cout1, Cout2);
  ledcWrite(Cchan1, Cout1); ledcWrite(Cchan2, Cout2);
  Derror = Dgoal - DcalculatedPos;
  pidController(Derror, DprevError, Dout1, Dout2);
  ledcWrite(Dchan1, Dout1); ledcWrite(Dchan2, Dout2);
  Eerror = Egoal - EcalculatedPos;
  pidController(Eerror, EprevError, Eout1, Eout2);
  ledcWrite(Echan1, Eout1); ledcWrite(Echan2, Eout2);
  Ferror = Fgoal - FcalculatedPos;
  pidControllerThumb(Ferror, FprevError, Fout1, Fout2);
  ledcWrite(Fchan1, Fout1); ledcWrite(Fchan2, Fout2);



  // update previous pot values and errors
  ArawPotValuePrev = ArawPotValue;
  AadjustedPrev = Aadjusted;
  AprevError = Aerror;

  BrawPotValuePrev = BrawPotValue;
  BadjustedPrev = Badjusted;
  BprevError = Berror;

  CrawPotValuePrev = CrawPotValue;
  CadjustedPrev = Cadjusted;
  CprevError = Cerror;

  DrawPotValuePrev = DrawPotValue;
  DadjustedPrev = Dadjusted;
  DprevError = Derror;

  ErawPotValuePrev = ErawPotValue;
  EadjustedPrev = Eadjusted;
  EprevError = Eerror;

  FrawPotValuePrev = FrawPotValue;
  FadjustedPrev = Fadjusted;
  FprevError = Ferror;


  Serial.print(Fgoal);
  Serial.print("    ");
  Serial.println(FcalculatedPos);



  delay (3);
}

float getMotorPos (float calculatedPos, int rawPotVal, int prevRawPotVal){

  float UpdatedMotorPos = 10;
  int totalSpins = int(calculatedPos);

  float fraction = (rawPotVal*1.0)/4097.0;
  if(fraction>0.99){fraction = .99;}

  // figure out if we completed a full rotation, and in what direction
  if(rawPotVal<500 && prevRawPotVal>3600){ totalSpins +=1; }
  if(rawPotVal>3600 && prevRawPotVal<500){ totalSpins -=1;}


  UpdatedMotorPos = totalSpins*1.0+fraction*1.0;
  
  if(UpdatedMotorPos-calculatedPos>.5){
    totalSpins-=1;
    UpdatedMotorPos = totalSpins*1.0+fraction*1.0;
    //Serial.println("problemmmmmmmmmmmmmmmmmmmmmmmmmm");
  }
   
     
  if(UpdatedMotorPos-calculatedPos<-.5){
    totalSpins+=1;
    UpdatedMotorPos = totalSpins*1.0+fraction*1.0;
    //Serial.println("problemmmmmmmmmmmmmmmmmmmmmmmmmm");
  }



  return UpdatedMotorPos;
  
}

void pidController (float error, float prevError, int & out1, int & out2){

  int pwmOut = 0;
  float errorDerriv = (error-prevError);
  pwmOut = kp*error + kd*errorDerriv;     // implement pd controller
  if(abs(error)<.07){pwmOut = 0;}               //prevents vibrations and power draw at low errrors
  if(abs(pwmOut)<35){pwmOut = 0;}

  pwmOut = int(abs(pwmOut));                   //must be positive
  pwmOut = constrain(pwmOut,0,motorLimit);// constrain maximum speed

  if (error<0){         // switch motor direction based on error.
    out1 = pwmOut;
    out2 = 0;
    }
  else{
    out1 = 0;
    out2 = pwmOut;
  }
  //Serial.println(pwmOut);
}

void pidControllerThumb (float error, float prevError, int & out1, int & out2){

  int pwmOut = 0;
  float errorDerriv = (error-prevError);
  pwmOut = kpT*error + kdT*errorDerriv;     // implement pd controller
  if(abs(error)<0.04){pwmOut = 0;}               //prevents vibrations and power draw at low errrors
  if(abs(pwmOut)<35){pwmOut = 0;}

  pwmOut = int(abs(pwmOut));                   //must be positive
  pwmOut = constrain(pwmOut,0,motorLimit);// constrain maximum speed

  if (error<0){         // switch motor direction based on error.
    out1 = pwmOut;
    out2 = 0;
    }
  else{
    out1 = 0;
    out2 = pwmOut;
  }
}



float getThumbMotorPos (int adjusted){

  float UpdatedMotorPos;
  
  UpdatedMotorPos = (adjusted*1.0)/4097.0;

  return UpdatedMotorPos;  
}


float getMotorPos2 (float calculatedPos, int adjusted, int adjustedPrev){

  float UpdatedMotorPos;
  int totalSpins = int(calculatedPos);

  float fraction = (adjusted*1.0)/4097.0;
  float pFraction =(adjustedPrev*1.0)/4097.0;

  if(fraction>0.99){fraction = .99;}
  if(pFraction>0.99){pFraction = .99;}


  if(fraction-pFraction > .96){ totalSpins -=1; }
  if(fraction-pFraction < -.96){ totalSpins +=1;}

  UpdatedMotorPos = totalSpins*1.0+fraction*1.0;
  
  return UpdatedMotorPos;
  
}

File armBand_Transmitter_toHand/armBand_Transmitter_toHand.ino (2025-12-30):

#include <esp_now.h>
#include <WiFi.h>
#include <Wire.h>

uint8_t broadcastAddress[] = {0x6C, 0xC8, 0x40, 0x8A, 0x89, 0x58};

typedef struct struct_message {
  
    float Adest;
    float Bdest;
    float Cdest;
    float Ddest;
    float Edest;
    float Fdest;

} 
struct_message;
struct_message myData;
esp_now_peer_info_t peerInfo;

void OnDataSent(const uint8_t *mac_addr, esp_now_send_status_t status) {
  Serial.print("\r\nLast Packet Send Status:\t");
  Serial.println(status == ESP_NOW_SEND_SUCCESS ? "Delivery Success" : "Delivery Fail");
}

int manhDist(int trainPoint[], int newPoint[]){
  int dist = 0;
  for(int i=0;i<16;i++){
    dist = dist + abs(trainPoint[i]-newPoint[i]);
  }

  return (dist);
}

//pressure array variables
int line1 = 35;
int line2 = 34;
int line3 = 39;

int output1 = 13;
int output2 = 12;
int output3 = 14;
int output4 = 27;
int output5 = 26;
int output6 = 25;
int output7 = 33;
int output8 = 32;

int pressure1 = 0;
int pressure2 = 0;
int pressure3 = 0;

int avg;
int completeArray[16];


int trainData[200][16]= {

    {0,0,523,218,455,229,298,429,244,142,0,0,154,0,349,187},
    {0,0,284,98,350,402,326,289,386,459,0,0,347,80,456,291},
    {0,0,388,145,479,287,397,368,485,283,0,0,232,16,453,331},
    {0,0,448,176,419,270,417,432,394,190,0,0,143,0,386,217},
    {0,0,432,181,479,222,272,435,278,129,0,0,186,0,335,167},
    {0,0,264,102,361,440,343,291,373,432,0,0,326,87,427,287},
    {0,0,437,173,477,279,400,373,455,270,0,0,197,12,464,343},
    {0,0,492,208,433,286,422,422,404,199,0,0,176,0,358,214},
    {0,0,492,205,544,231,240,449,339,145,0,0,190,0,336,176},
    {0,0,255,87,365,441,341,302,383,432,0,0,323,46,443,273},
    {0,0,436,165,495,271,419,422,469,257,0,0,208,2,511,385},
    {0,0,463,185,475,291,395,432,381,185,0,0,177,0,366,222},
    {0,0,507,199,599,257,240,447,287,144,0,0,129,0,330,163},
    {0,0,275,107,351,434,316,291,355,403,0,0,305,75,416,272},
    {0,0,431,161,468,279,361,368,478,265,0,0,210,4,507,354},
    {0,0,446,167,431,240,400,447,368,176,0,0,166,0,404,242},
    {0,0,510,201,549,240,251,417,352,162,0,0,191,0,314,181},
    {0,0,272,129,357,433,304,290,359,397,0,0,297,79,433,287},
    {0,0,450,177,484,240,286,387,448,245,0,0,223,13,470,317},
    {0,0,450,195,424,272,389,410,409,158,0,0,160,0,384,214},


    {0,0,510,189,579,243,249,419,304,155,0,0,166,0,325,187},
    {0,0,294,97,401,407,320,274,390,451,0,0,318,71,448,301},
    {0,0,445,179,499,293,368,386,466,253,0,0,217,11,483,349},
    {0,0,449,188,484,305,379,422,415,187,0,0,176,0,365,229},
    {0,0,528,199,501,240,256,424,304,146,0,0,178,0,318,192},
    {0,0,294,96,370,427,310,286,383,432,0,0,325,72,474,311},
    {0,0,418,169,480,288,347,369,438,230,0,0,229,22,511,339},
    {0,0,389,174,461,289,388,398,413,179,0,0,177,0,384,240},
    {0,0,255,186,585,261,378,405,325,186,0,0,227,0,429,205},
    {0,0,237,80,336,409,385,264,310,432,0,0,354,78,409,318},
    {0,0,351,159,463,336,487,388,364,276,0,0,274,29,431,304},
    {0,0,177,110,591,333,496,460,272,180,0,36,397,54,354,176},
    {0,0,231,115,598,282,391,470,273,151,0,0,314,0,399,144},
    {0,0,249,98,338,381,371,267,301,427,0,0,351,94,382,304},
    {0,0,275,122,470,350,523,375,359,304,0,0,333,26,415,323},
    {0,0,163,87,511,362,620,442,330,198,0,0,454,78,368,191},
    {0,0,265,143,590,277,425,481,293,182,0,0,255,0,395,170},
    {0,0,239,90,371,415,387,267,315,427,0,0,340,84,425,315},
    {0,0,315,144,490,320,480,368,361,290,0,0,374,55,418,327},
    {0,0,131,80,506,338,598,423,357,222,0,0,429,73,405,207},


    {0,0,246,134,645,265,400,477,288,160,0,0,285,2,358,161},
    {0,0,238,82,336,376,354,268,291,400,0,0,328,100,366,302},
    {0,0,284,146,510,314,464,377,366,278,0,0,395,58,400,304},
    {0,0,133,83,511,336,592,426,389,226,0,0,464,85,374,208},
    {0,0,246,138,577,230,422,496,369,191,0,0,261,2,400,174},
    {0,0,224,47,352,379,368,269,306,397,0,0,329,80,349,322},
    {0,0,279,124,502,311,473,390,368,275,0,0,400,25,409,304},
    {0,0,172,90,505,327,594,426,337,220,0,0,464,79,390,212},
    {0,0,241,134,615,257,400,487,307,173,0,0,251,0,379,171},
    {0,0,237,106,355,381,369,263,315,404,0,0,336,96,387,301},
    {0,0,304,144,542,328,464,382,398,291,0,0,411,71,442,310},
    {0,0,144,80,559,350,573,454,355,244,0,0,496,87,381,222},
    {0,0,250,138,644,246,403,496,313,172,0,0,366,32,394,178},
    {0,0,242,112,350,396,359,240,313,401,0,0,343,94,388,303},
    {0,0,267,128,488,320,440,365,368,272,0,0,448,80,417,304},
    {0,0,107,64,508,346,592,415,366,208,0,0,528,96,432,220},
    {0,0,227,128,602,252,379,464,368,176,0,0,400,37,370,173},
    {0,0,230,104,336,396,354,246,293,381,0,0,326,102,364,304},
    {0,0,298,146,554,327,489,385,374,257,0,0,428,68,427,286},
    {0,0,104,55,587,365,599,463,366,234,0,0,561,112,354,214},


    {0,0,384,218,628,274,373,464,276,161,0,0,160,0,407,205},
    {0,0,267,93,401,415,399,254,365,460,0,0,304,42,400,368},
    {0,0,374,147,490,257,462,406,384,272,0,0,192,0,475,337},
    {0,0,226,128,449,301,598,423,400,256,0,0,336,35,407,240},
    {0,0,371,175,592,243,363,469,364,163,0,0,176,0,419,185},
    {0,0,233,84,354,401,398,272,336,432,0,0,297,67,382,336},
    {0,0,389,179,506,299,434,387,419,259,0,0,262,33,457,320},
    {0,0,208,91,523,348,543,421,412,256,0,0,336,27,421,237},
    {0,0,342,154,624,247,374,511,374,171,0,0,213,0,435,180},
    {0,0,235,95,350,400,390,274,334,415,0,0,299,66,400,339},
    {0,0,375,166,533,320,460,410,400,242,0,0,246,26,446,333},
    {0,0,240,121,510,351,551,403,377,240,0,0,400,28,432,282},
    {0,0,320,164,599,266,356,450,378,174,0,0,128,0,398,198},
    {0,0,254,98,378,389,393,253,342,405,0,0,284,64,403,345},
    {0,0,336,153,506,307,434,390,383,270,0,0,319,33,470,333},
    {0,0,231,112,459,332,589,425,413,225,0,0,351,16,451,263},
    {0,0,335,154,592,272,384,448,386,179,0,0,251,0,373,187},
    {0,0,258,112,336,368,365,266,333,415,0,0,289,70,368,329},
    {0,0,238,150,510,336,496,388,434,266,0,0,273,27,507,331},
    {0,0,212,114,523,355,542,400,448,351,0,0,362,36,427,272},
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

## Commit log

2025-12-30 arm band code that controls the hand
2025-12-30 Reciever code to train arm band
    This code runs on an esp connected to the computer while the armband is running. You type a number in the monitor (corresponding to a hand gesture) and hit enter, and it will print a line of sensor d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
2025-12-30 Stls for 3d printed parts.
    Not in an assembly unfortunately. If I were you I'd look at these but design my own.
    [bbCarrier.stl, bbcarrier2.stl, detents.stl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]
2025-12-30 Circuit Schematic. Hope it's actually correct
2025-12-30 sensor data
    [sensorsData.csv]
